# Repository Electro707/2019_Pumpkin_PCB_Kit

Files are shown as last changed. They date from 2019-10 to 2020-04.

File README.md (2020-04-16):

# 2019_Pumpkin_PCB_Kit
A soldering kit in the shape of a pumkpin. Designed for one of many UNH makerspace's soldering events

This repository is archived, as it's a one-time design.
Now files are hosted on Google Drive.

Link to website, in which the Google Drive link can be found:
[Link](https://electro707.com/documentation/PCB/2019_Pumpkin/index.php)

I may create a new general reposity for the kit that will be updated as time goes on 
(there also won't be any of the University of New Haven logos on that one).

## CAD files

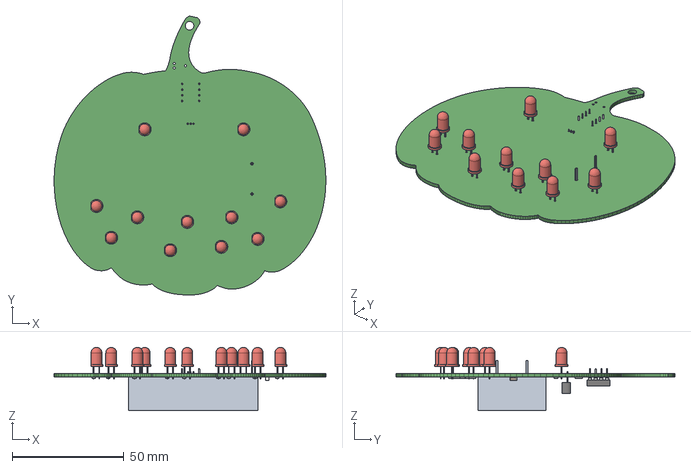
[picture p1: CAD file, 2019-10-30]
CAD-Inventor/PCB.step
121.6 x 124.9 x 28.3 mm

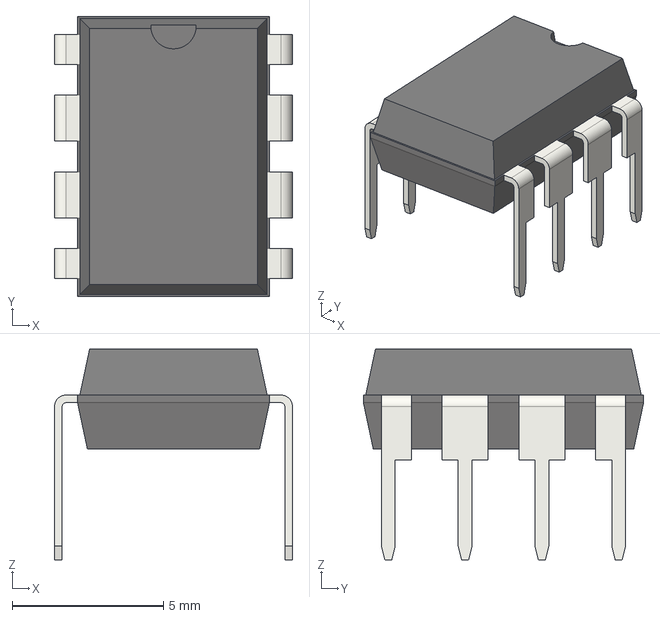
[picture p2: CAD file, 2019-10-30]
CAD-Inventor/DIP-8_W7.62mm.step
7.87 x 9.27 x 6.98 mm

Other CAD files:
CAD-Inventor/Drawing.dwg
CAD-Inventor/Assembly-PCB alone.iam
CAD-Inventor/ExplodedView.ipn

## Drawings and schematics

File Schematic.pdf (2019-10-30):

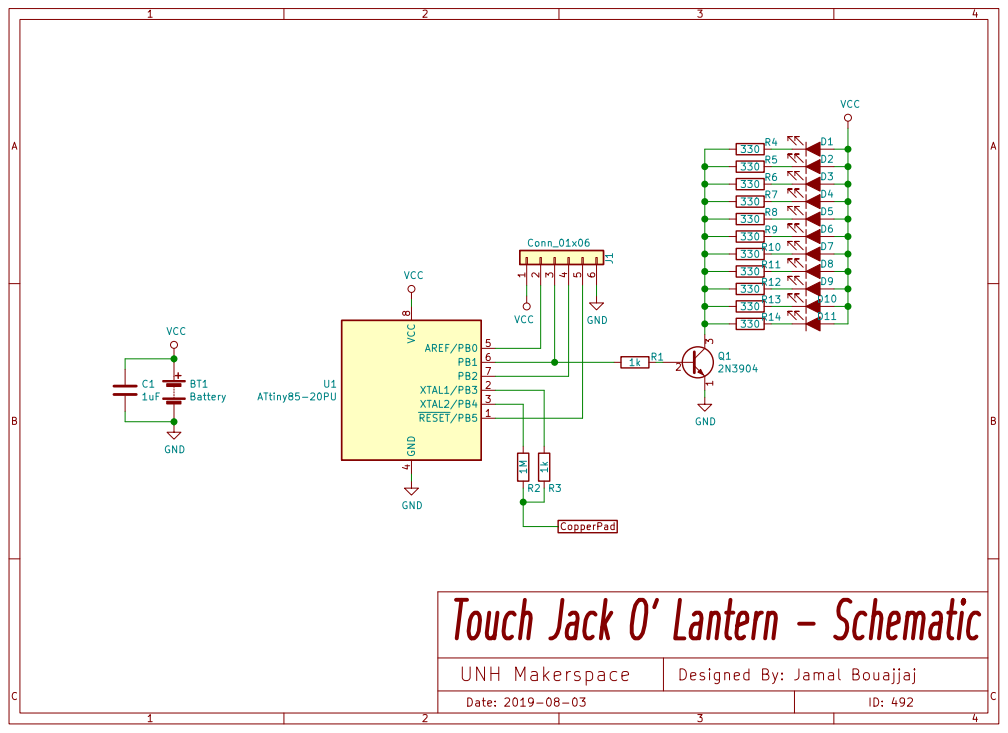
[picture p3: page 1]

Touch Jack O' Lantern - Schematic

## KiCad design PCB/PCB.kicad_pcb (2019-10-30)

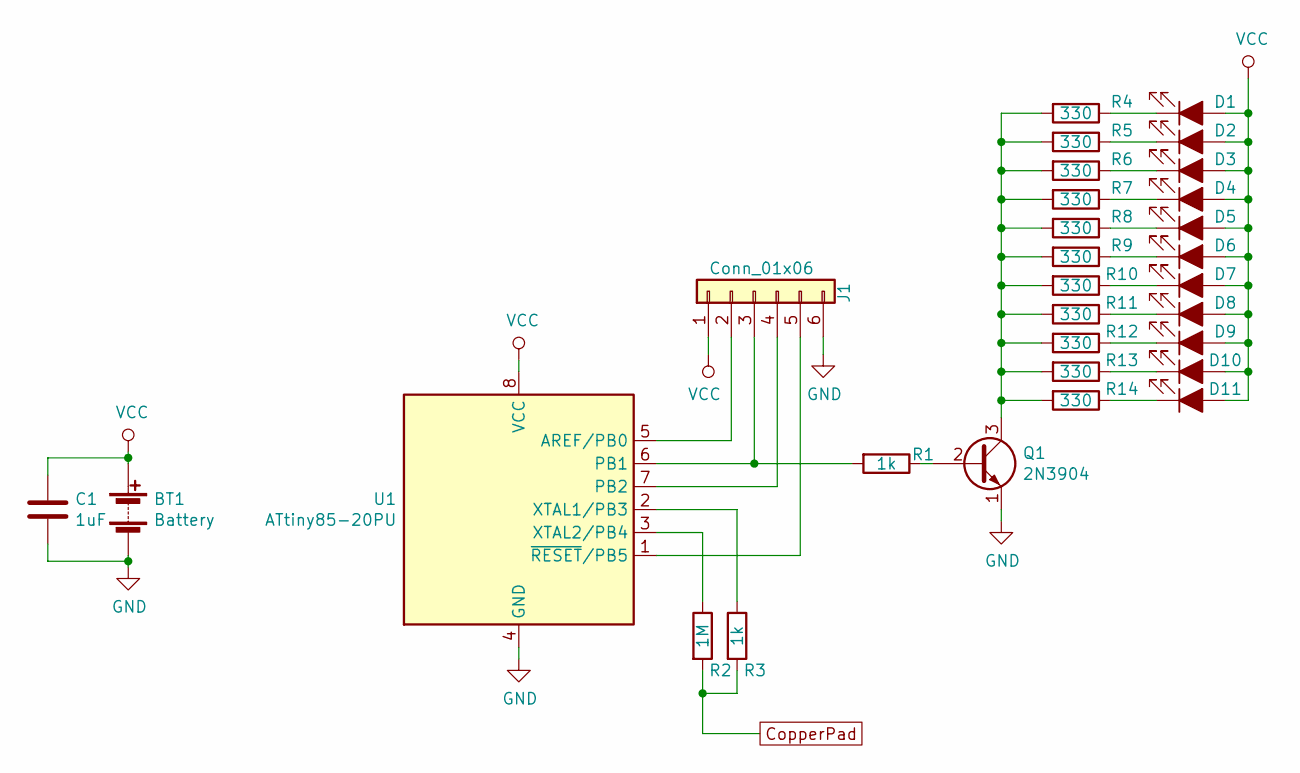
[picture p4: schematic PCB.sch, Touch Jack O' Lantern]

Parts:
BT1: Battery; BC2AAPC
C1: 1uF; C_1206_3216Metric_Pad1.42x1.75mm_HandSolder
D1, D2, D3, D4, D5, D6, D7, D8, D9, D10, D11: LED_ALT; LED_D5.0mm
J1: Conn_01x06; Tag-Connect_TC2030-IDC-NL_2x03_P1.27mm_Vertical
Q1: 2N3904; TO-92_Inline
R1, R3: 1k; R_1206_3216Metric_Pad1.42x1.75mm_HandSolder
R2: 1M; R_1206_3216Metric_Pad1.42x1.75mm_HandSolder
R4, R5, R6, R7, R8, R9, R10, R11, R12, R13, R14: 330; R_1206_3216Metric_Pad1.42x1.75mm_HandSolder
U1: ATtiny85-20PU; DIP-8_W7.62mm_Socket

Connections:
CopperPad: R2.2, R3.2
GND: BT1.2 (-), C1.2, J1.6, Q1.1 (E), U1.4 (GND)
unnamed: D1.1 (K), R4.1
unnamed: D2.1 (K), R5.1
unnamed: D3.1 (K), R6.1
unnamed: D4.1 (K), R7.1
unnamed: D5.1 (K), R8.1
unnamed: D6.1 (K), R9.1
unnamed: D7.1 (K), R10.1
unnamed: D8.1 (K), R11.1
unnamed: D9.1 (K), R12.1
unnamed: D10.1 (K), R13.1
unnamed: D11.1 (K), R14.1
unnamed: J1.2, U1.5 (AREF/PB0)
unnamed: J1.3, R1.2, U1.6 (PB1)
unnamed: J1.4, U1.7 (PB2)
unnamed: J1.5, U1.1 (~RESET~/PB5)
unnamed: Q1.2 (B), R1.1
unnamed: Q1.3 (C), R4.2, R5.2, R6.2, R7.2, R8.2, R9.2, R10.2, R11.2, R12.2, R13.2, R14.2
unnamed: R2.1, U1.3 (XTAL2/PB4)
unnamed: R3.1, U1.2 (XTAL1/PB3)
VCC: BT1.1 (+), C1.1, D1.2 (A), D2.2 (A), D3.2 (A), D4.2 (A), D5.2 (A), D6.2 (A), D7.2 (A), D8.2 (A), D9.2 (A), D10.2 (A), D11.2 (A), J1.1, U1.8 (VCC)

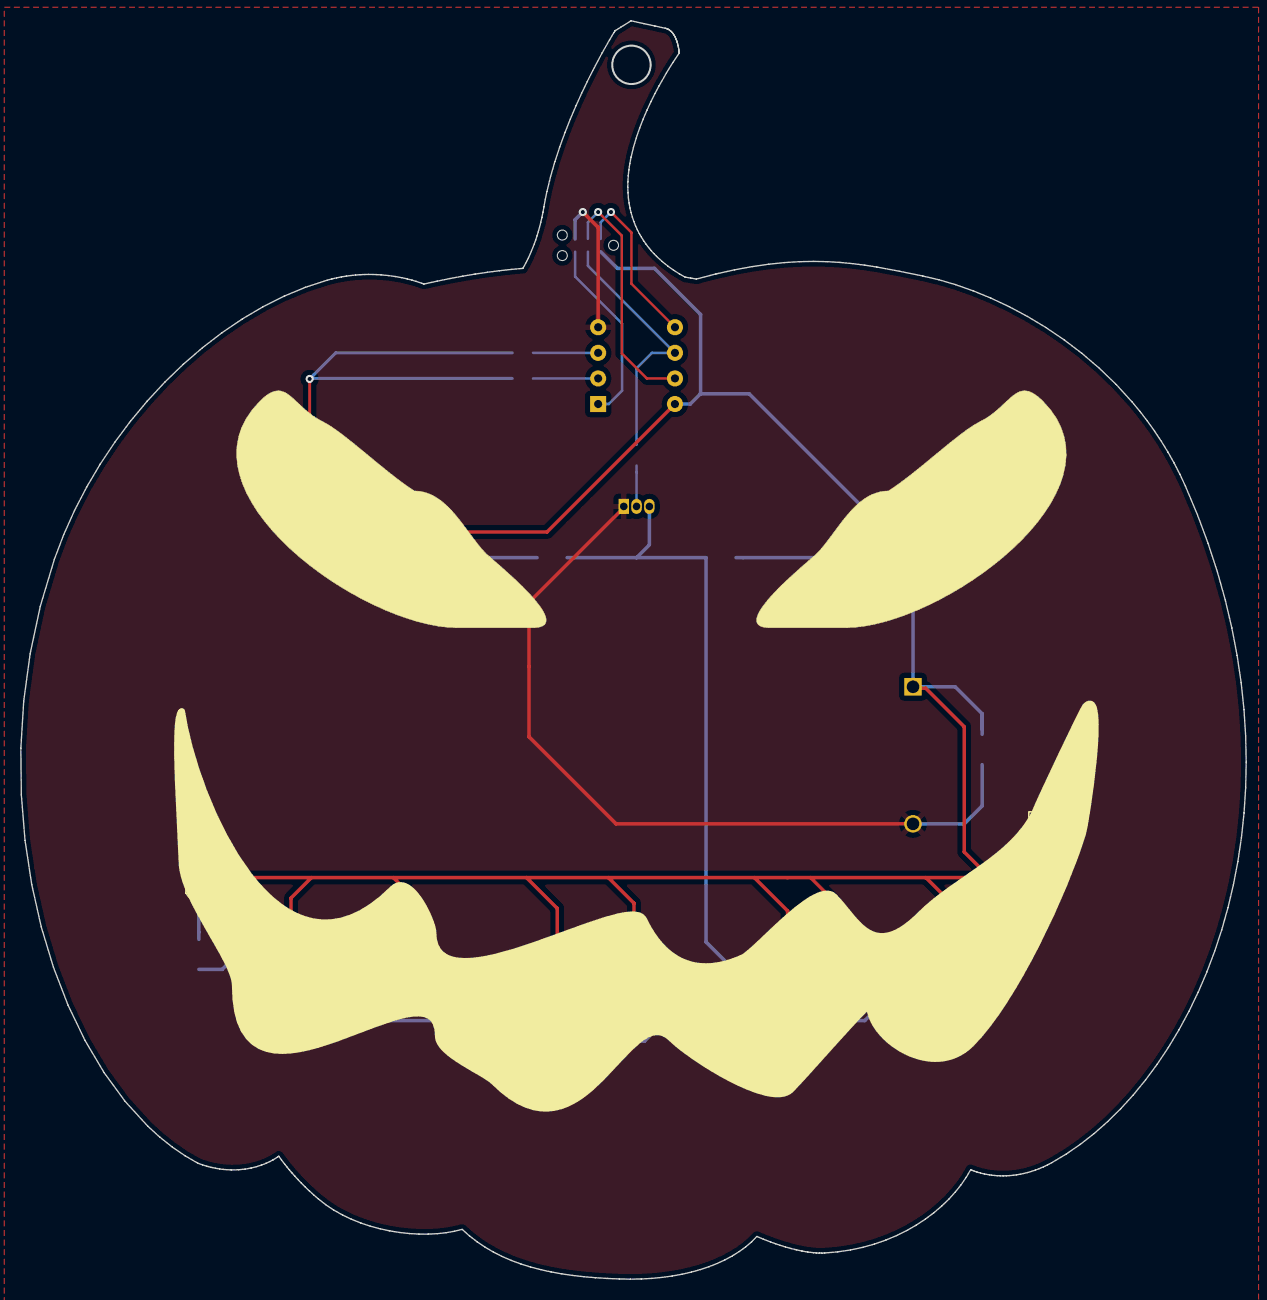
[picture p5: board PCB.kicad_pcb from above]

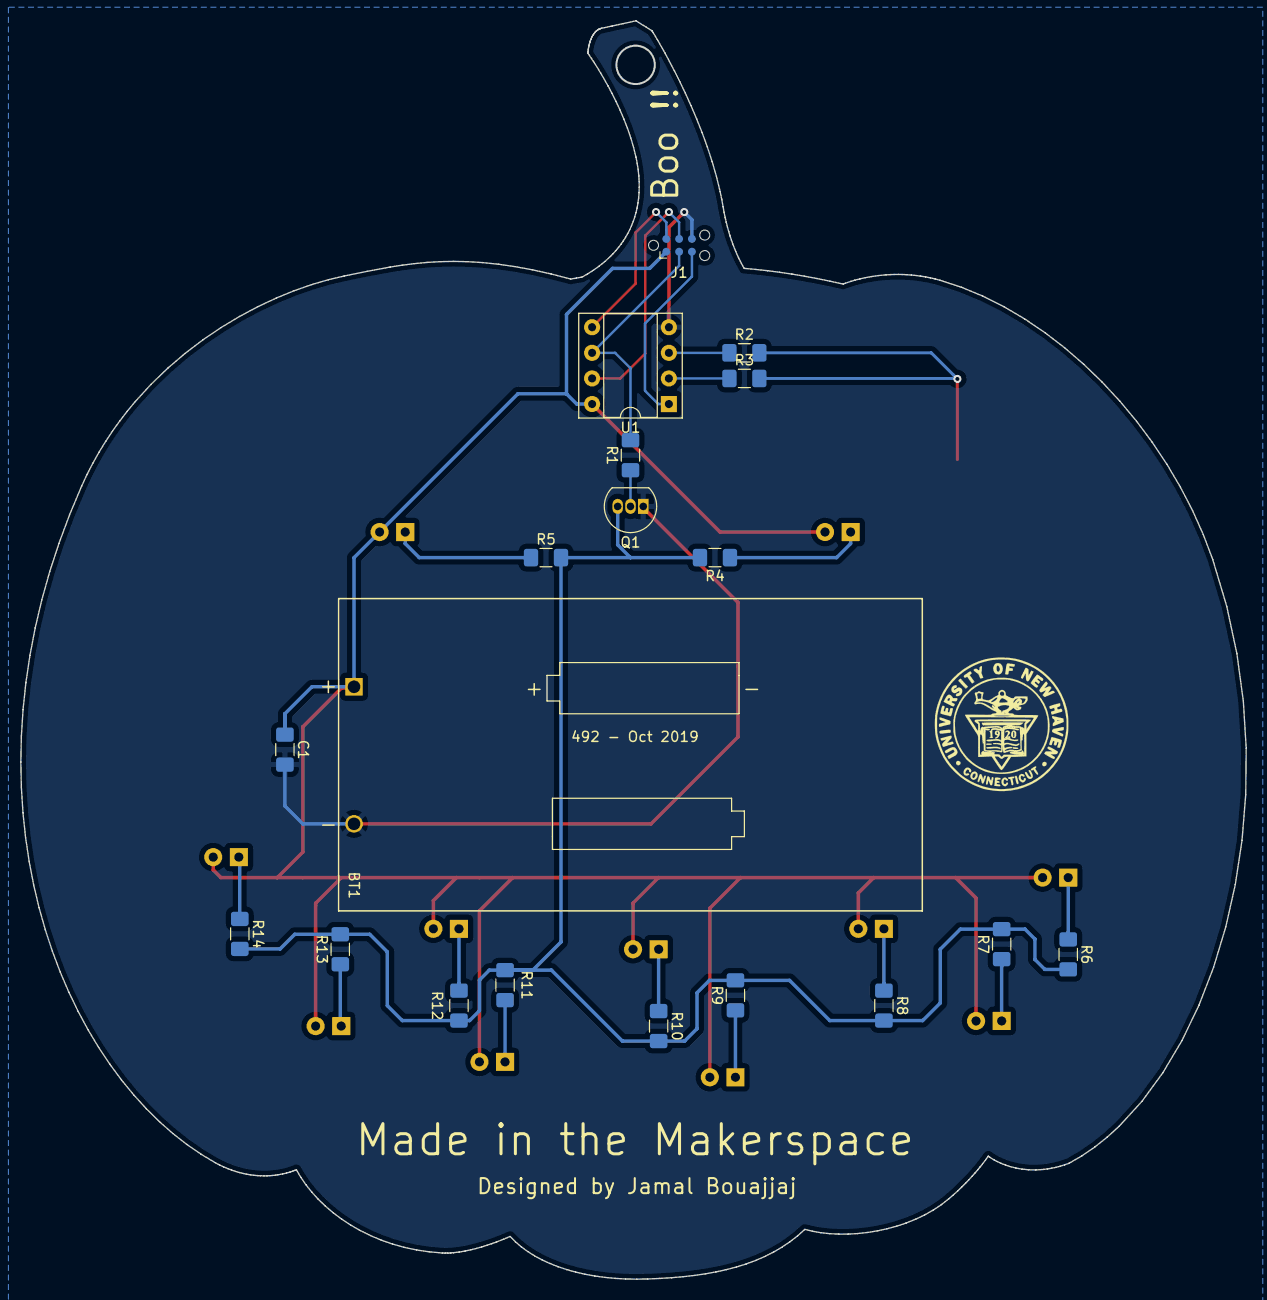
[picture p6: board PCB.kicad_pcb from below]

Board: 2 copper layers, 121.6 x 124.9 mm, 30 parts (19 on the bottom side), 22 nets.

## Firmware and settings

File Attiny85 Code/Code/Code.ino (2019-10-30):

/************************************************************************************************************************
 *  Touch Pumpkin Attiny85 Code
 *  By Jamal Bouajjaj
 *
 *  This program controls the LEDs on the 2019 UNH Makerspace Touch Pumpkin soldering kit. This program will wait for
 *    a capacitive touch to reach above a threshold, in which case it will switch the LED mode to fading, blinking, and
 *    off sequentially.
************************************************************************************************************************/
#include <CapacitiveSensor.h>     // Import the library
#define LEDPIN PB1                // Define the LED pin
#define CAPSENSE_SEND PB4         // Define the capacitive touch send pin
#define CAPSENSE_REC  PB3         // Define the capacitive touch recieve pin

int mode = 0;                     // Store the current LED mode
bool last_state = false;          // Store the last capacitive touch state ( pressed or not pressed)
int pwm_val = 0;                  // Store the PWM value during fading mode
bool pwm_direction = false;       // Store the directions of the changing PWM during fading mode ( fade up or down)
int old_millis = 0;               // Store the previous time (millis()) during blinking and fading mode
int current_time = 0;             // Store the current time (millis()) for comparision with old_millis

CapacitiveSensor   cs = CapacitiveSensor(CAPSENSE_SEND, CAPSENSE_REC);   // Create the CapacitiveSensor class

void setup()                    
{
   cs.set_CS_AutocaL_Millis(0xFFFFFFFF);     // Turn off autocalibrate on the capacitive touch channel
   pinMode(PB1, OUTPUT);                      // Set the LED pin as an output
   // The following code is to save power on unused preiferals
   ACSR |= (1<<ACD);              // Turn off Analog Comparator
   ADCSRA &= (1<<ADEN);           // Turn off ADC
   PRR |= (1<<PRADC);             // Shut down ADC
}

void loop()                    
{
    long cs_val =  cs.capacitiveSensor(30);     // Detect the arbritrary capacitance on the copper pad

    // If above threshold and previous state is off, increment the operating mode
    if(cs_val > 110){
      if(last_state == false){    // If pressed and the previous state is off, change the mode
        last_state = true;
        pwm_val = 0;
        pwm_direction = 0;
        mode++;
        if(mode > 2){
          mode = 0;
        }
        digitalWrite(LEDPIN, 0);
        if(mode == 2){
          digitalWrite(LEDPIN, 1);
        }
        old_millis = millis();
        delay(150);
      }
    }
    else{   // If the previous press state is on and the pad isn't pressed, revert the previous pressed state to false
      if(last_state == true){
        last_state = false;
        delay(50);
      }
    }

    // Drive the LEDs based on the current operating mode
    switch(mode){
      case 0:       // Mode 0 <- Off
        digitalWrite(LEDPIN, 0);
      break;
      
      case 1:       // Mode 1 <- Fading
        current_time = millis();
        if(current_time - old_millis >= 20){
          old_millis = millis();
          if(pwm_direction){
            if(pwm_val == 0){
              pwm_direction = false;
            }
            else{
              pwm_val--;
            }
          }
          else{
            if(pwm_val >= 100){
              pwm_direction = true;
            }
            else{
              pwm_val++;
            }
          }
        }
        analogWrite(LEDPIN, pwm_val);
       
      break;
      case 2:     // Mode 2 <- Blinking
        current_time = millis();
        if(current_time - old_millis >= 1000){
          digitalWrite(LEDPIN, !digitalRead(LEDPIN));
          old_millis = millis();
        }
      break;
    }
}

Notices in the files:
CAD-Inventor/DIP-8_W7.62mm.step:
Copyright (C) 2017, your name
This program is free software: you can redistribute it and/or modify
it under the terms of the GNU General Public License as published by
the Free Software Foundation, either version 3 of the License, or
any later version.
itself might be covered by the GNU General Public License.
